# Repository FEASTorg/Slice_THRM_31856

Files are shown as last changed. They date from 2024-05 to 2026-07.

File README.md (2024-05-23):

<div align="center">
  <!-- Title: -->
  <a href="https://github.com/uwo-fast">
    
  </a>
  <h2><a href="https://github.com/uwo-fast/Slice_THRM"> Slice THRM </a></h2>
  <!-- Labels: -->
  <!-- First row: -->
  <a href="https://github.com/uwo-fast/.github/blob/main/collaborating.md">
    
  </a>
  <a href="https://github.com/uwo-fast/.github/blob/main/contributing.md">
    
  </a>
  <a href="https://www.appropedia.org/Category:FAST_literature_reviews">
    
  </a>
  <a href="https://certification.oshwa.org/">
    
    <!-- img src="https://img.shields.io/badge/OSHWA-Certified-darkgreen?style=flat-square" height="20" alt="OSHWA" -->       <!-- img src="https://img.shields.io/badge/OSHWA-Pending-darkorange?style=flat-square" height="20" alt="OSHWA" -->
  </a>
  <a href="https://osf.io/">
    
  </a>
  <a href="https://doi.org">
    
  </a>
  <!-- Second row: -->
  <br>
  <a href="https://github.com/uwo-fast/Slice_THRM/blob/main/LICENSE">
    
  </a>
  <a href="https://github.com/uwo-fast/Slice_THRM">
    
  </a>
  <a href="https://github.com/uwo-fast/Slice_THRM/issues">
    
  </a>
  <a href="https://github.com/uwo-fast/Slice_THRM/network/members">
    
  </a>
  <a href="https://github.com/uwo-fast/Slice_THRM/stargazers">
    
  </a>
  <!-- Short description: -->
  <h3>Thermocouple Reader Slice for BREAD.</h3>
</div>

## Introduction
[Provide a brief introduction to the project, including the motivation and goals. Explain the significance and context of the research.]

## Project Overview
[Describe the project in more detail. This section can be split into subsections if necessary.]

## Installation
[Provide instructions for installing any necessary software or hardware components.]

## Usage
[Explain how to use the project. Include examples and screenshots if applicable.]

### Basic Usage
[Provide basic usage instructions.]

### Advanced Usage
[Provide advanced usage instructions, including any optional features or configurations.]

## Documentation
[Link to the detailed documentation if available. Provide instructions on how to access and navigate the documentation.]

## Contributing
[Explain how others can contribute to the project. Include guidelines for submitting issues, pull requests, and any coding standards.]

### Code of Conduct
[Link to the project's code of conduct if available.]

## License
[State the license under which the project is distributed. Include a link to the full license text.]

## Acknowledgements
[Acknowledge any contributors, collaborators, funding sources, or organizations that supported the project.]

## Contact
[Provide contact information for the project maintainer(s) or lead researcher(s). Include an email address or a link to a contact form.]

---

<div align="center">
  <p>
    
    
  </p>
</div>

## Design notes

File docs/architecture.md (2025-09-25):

---
title: "Architecture Overview"
description: "High-level architecture: electrical, firmware, and mechanical design notes."
---

Overview of the electrical, firmware, and mechanical design of this Slice.

## 🧠 Purpose

<!-- Briefly describe the function of the Slice -->

This Slice is designed to ...

## 🔌 Interfaces

| Signal | Connector | Direction | Voltage | Notes |
| --- | --- | --- | --- | ----- |
| ... | ... | ... | ... | ... |

## 🪛 MCU Pin Mapping

| MCU Pin | Function | Net | Notes |
| --- | --- | --- | ----- |
| ... | ... | ... | ... |

## 🔋 Power Domains

- Logic power: ...
- High-current domain: ...

## 🧩 Mechanical

- Mounting pattern: ...
- Dimensions: ...
- Notes: ...

---

<!-- Optional: Add block diagrams or images under docs/assets/ -->

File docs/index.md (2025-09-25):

---
title: "Slice THRM 31856 Documentation"
description: "Overview and entry page for Slice THRM 31856 project documentation."
nav_exclude: true
---

Welcome to the Slice THRM 31856 project documentation.

## Board Renders

<figure style="display:inline-block; text-align:center; margin:10px;">
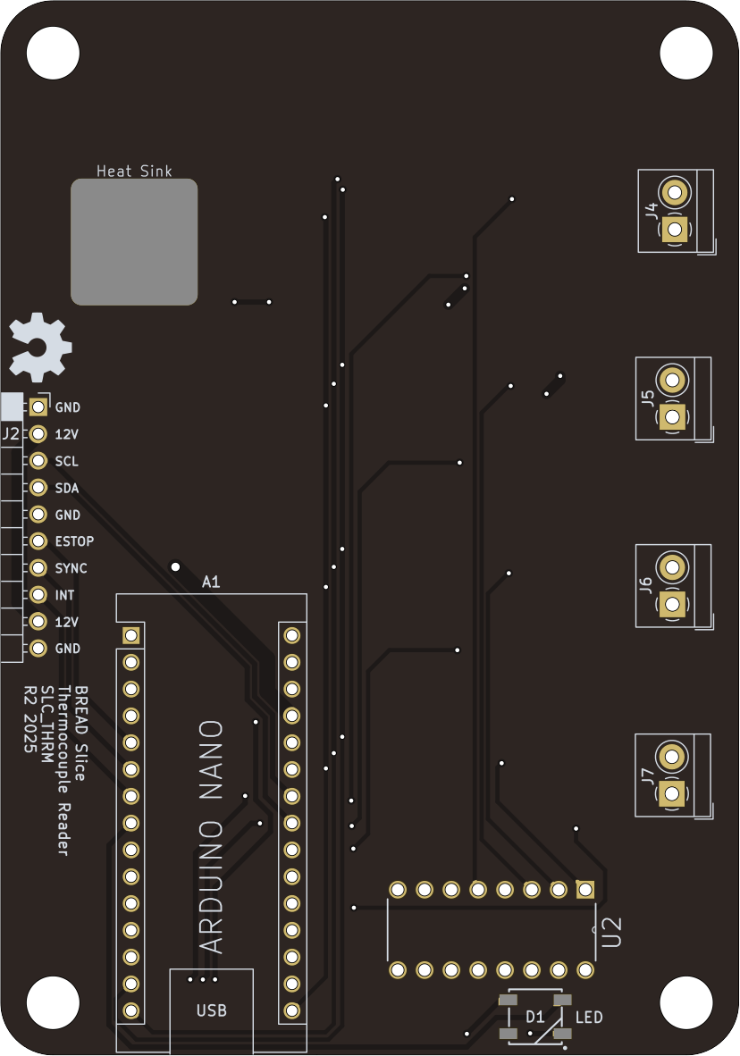
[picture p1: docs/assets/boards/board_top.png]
Board Top
  
  <figcaption>Top</figcaption>
</figure>

<figure style="display:inline-block; text-align:center; margin:10px;">
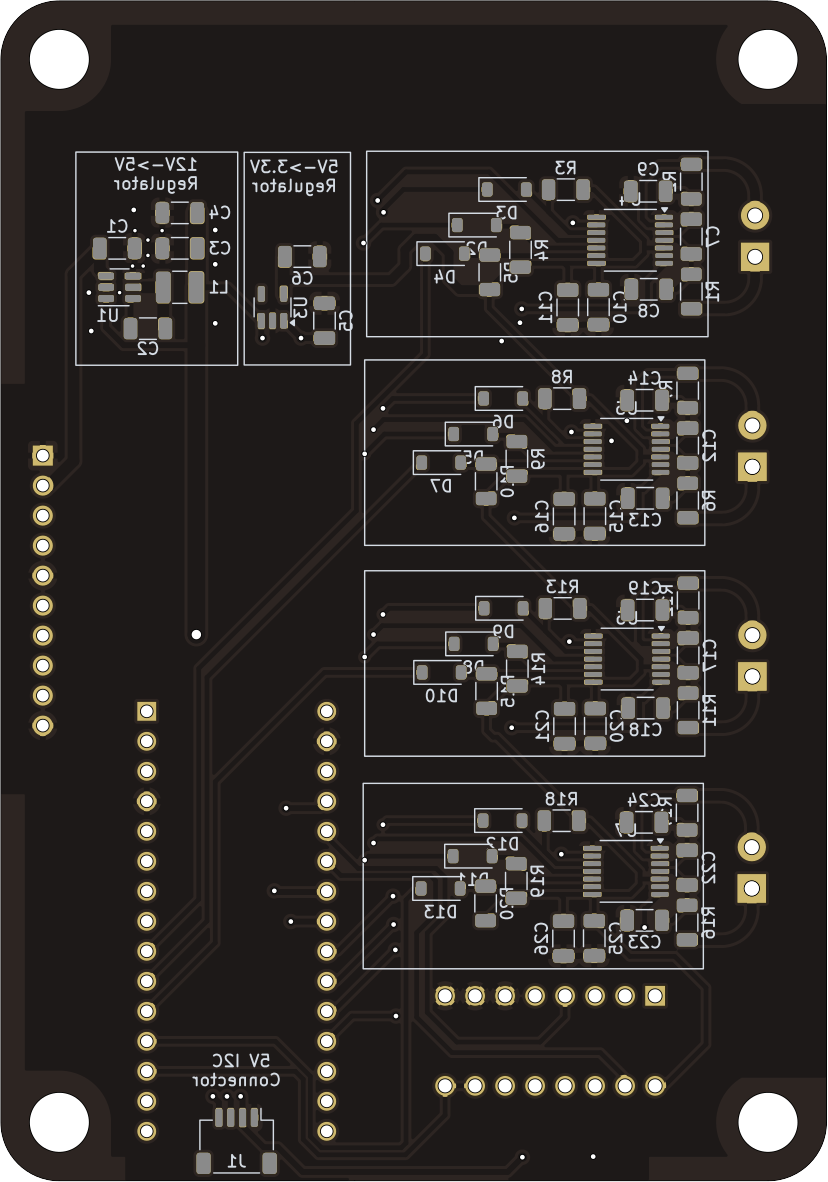
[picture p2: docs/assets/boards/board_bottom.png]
Board Bottom
  
  <figcaption>Bottom</figcaption>
</figure>

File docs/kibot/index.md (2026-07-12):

---
title: "KiBot Outputs"
description: "Index for KiBot-generated PCB artifacts."
layout: "page"
---

These are the docs & KiBot Outputs for Slice THRM 31856

The following files were generated from the latest PCB build:

- [Schematic.pdf](./Schematic.pdf)
- [PCB.pdf](./PCB.pdf)
- [kibot.log](./kibot.log)
- [BREAD_Slice-bom.html](./BREAD_Slice-bom.html)
- [BREAD_Slice-ibom.html](./BREAD_Slice-ibom.html)

_Last updated automatically on 2026-07-12 at 03:55:23 UTC by KiBot via GitHub Actions._

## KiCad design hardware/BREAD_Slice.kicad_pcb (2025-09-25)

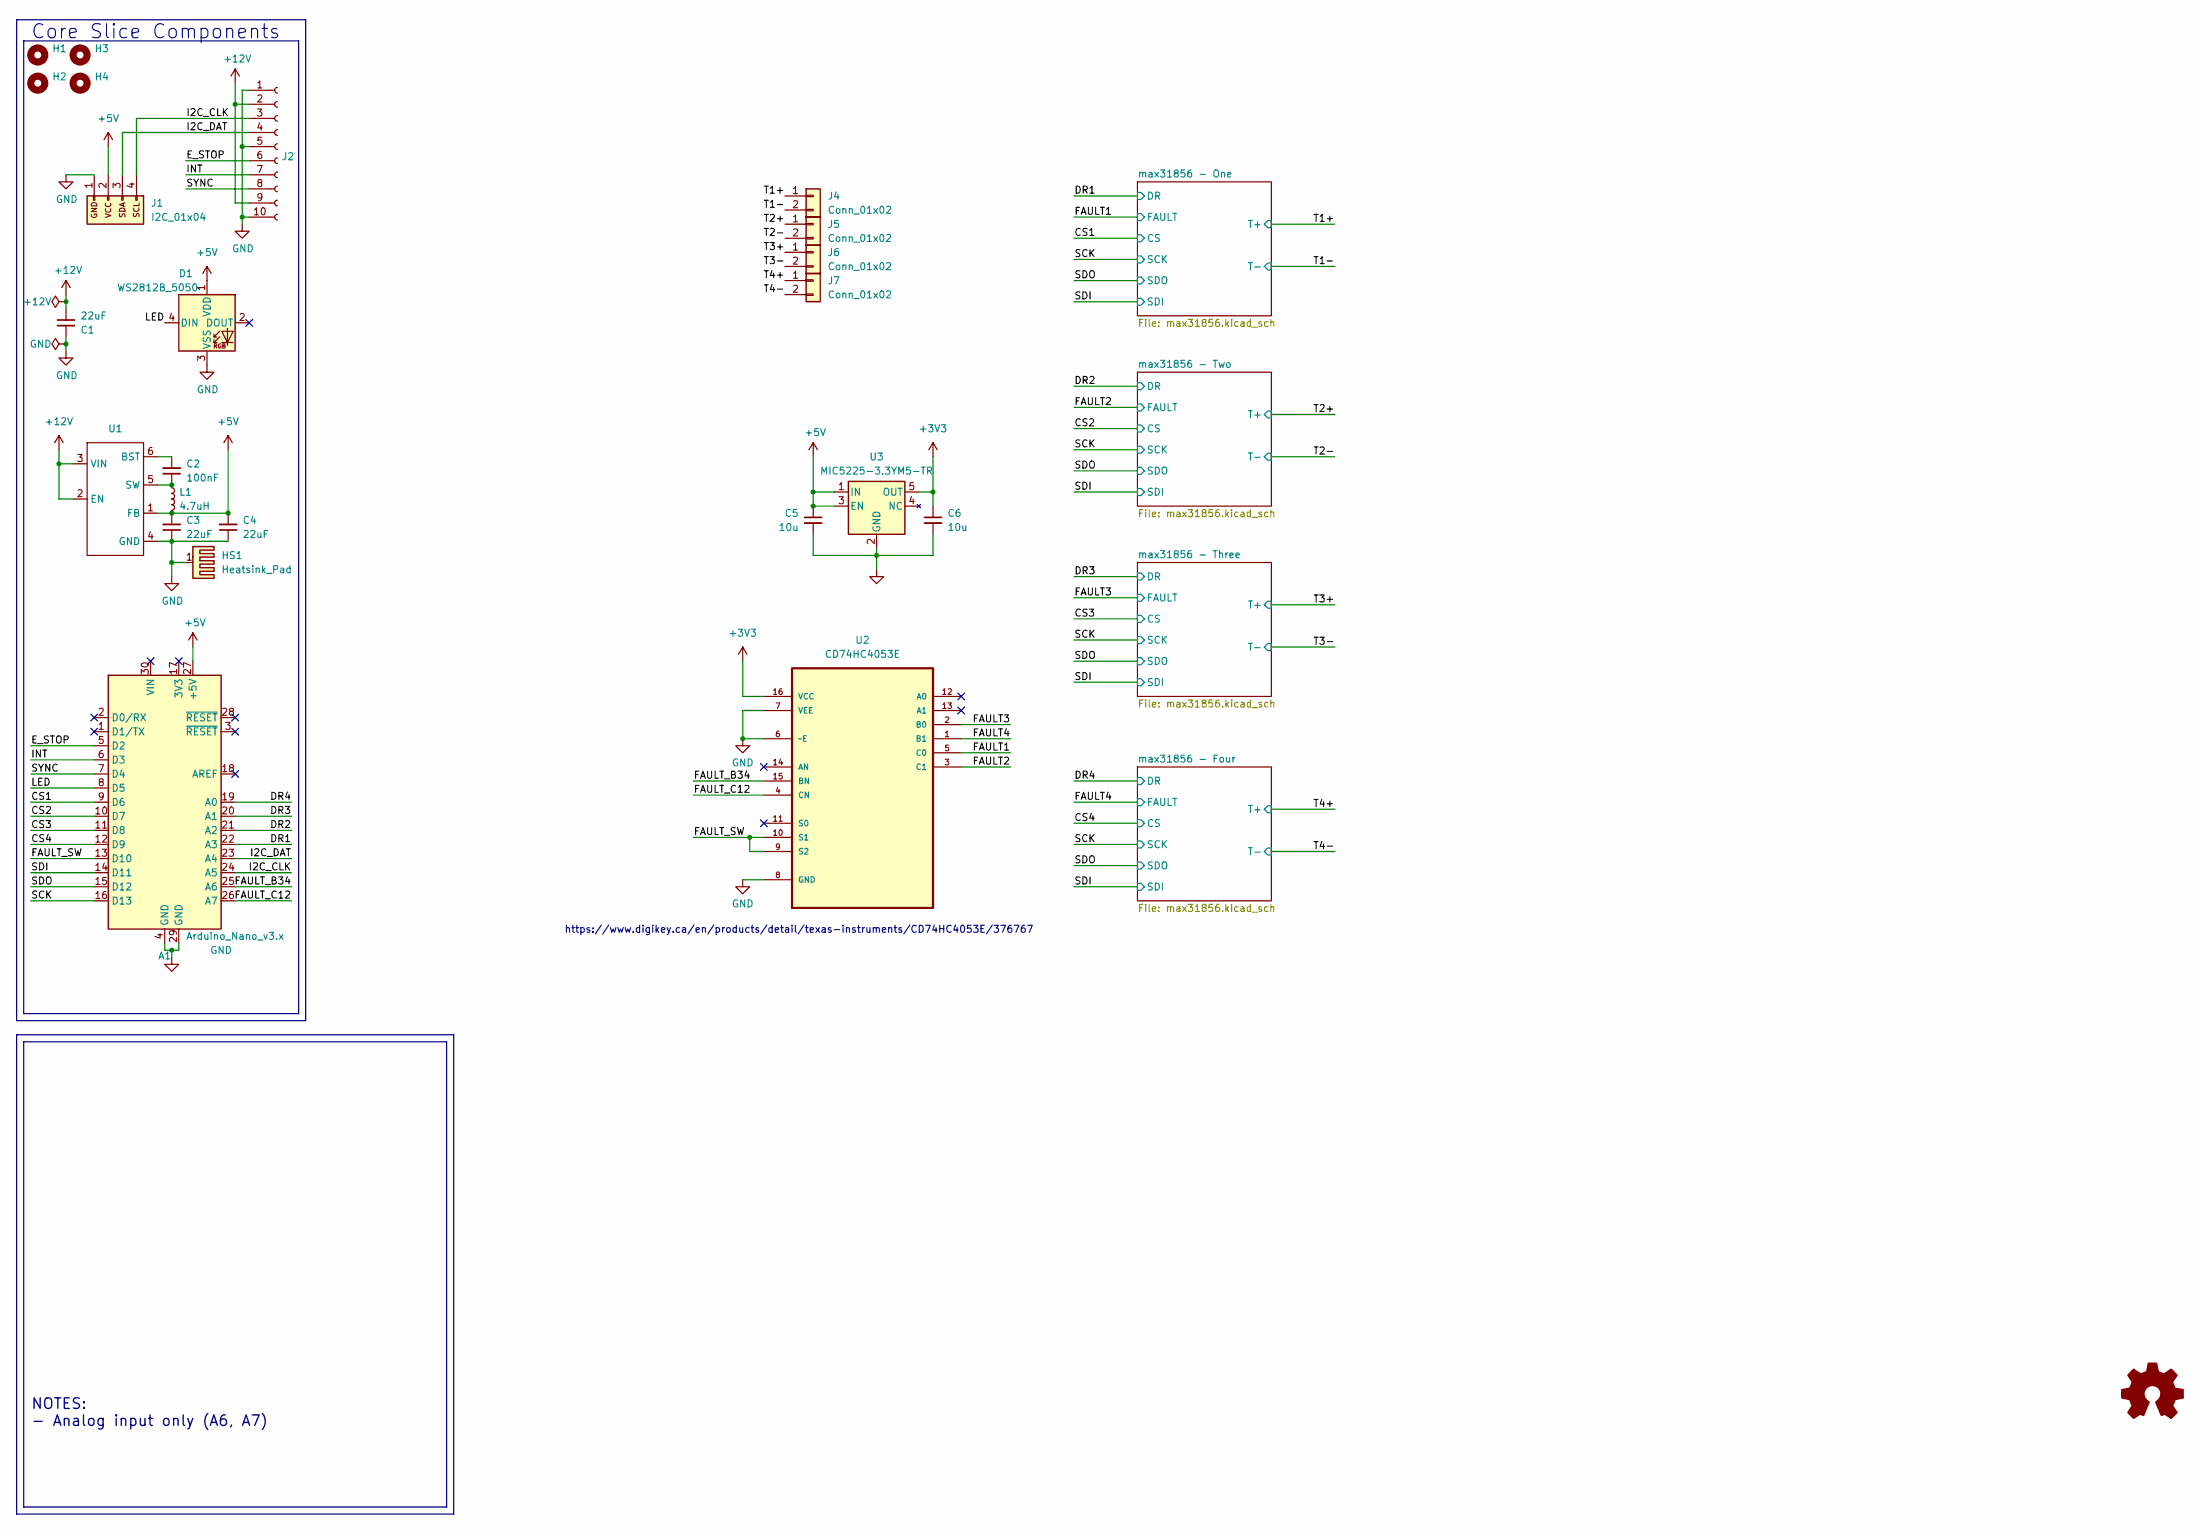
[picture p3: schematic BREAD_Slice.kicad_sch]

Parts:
A1: Arduino_Nano_v3.x; Arduino_Nano
C1, C3, C4: 22uF; C_1206_3216Metric
C2: 100nF; C_1206_3216Metric
C5, C6: 10u; C_1206_3216Metric
D1: WS2812B_5050; WS2812-5050-4PIN
H1, H2, H3, H4: MountingHole; MountingHole_5mm
HS1: Heatsink_Pad; Thermal Pad
J1: I2C_01x04; JST_SH_SM04B-SRSS-TB_1x04-1MP_P1.00mm_Horizontal
J2: Conn_01x10_Female; PinSocket_1x10_P2.54mm_Horizontal
J4, J5, J6, J7: Conn_01x02; TerminalBlock_4Ucon_1x02_P3.50mm_Horizontal
L1: 4.7uH; L_1210_3225Metric
U1: TSOT-23-6
U2: CD74HC4053E; DIP254P762X508-16; MPN CD74HC4053E
U3: MIC5225-3.3YM5-TR; SOT-23-5

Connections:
+3V3: C6.1, U2.16 (VCC), U3.5 (OUT); also elsewhere on the board
+5V: A1.27 (+5V), C3.2, C4.2, C5.1, D1.1 (VDD), J1.2, L1.2, U1.1 (FB), U3.1 (IN), U3.3 (EN)
+12V: C1.2, J2.2, J2.9, U1.2 (EN), U1.3 (VIN)
/CS1: A1.9 (D6); also elsewhere on the board
/CS2: A1.10 (D7); also elsewhere on the board
/CS3: A1.11 (D8); also elsewhere on the board
/CS4: A1.12 (D9); also elsewhere on the board
/DR1: A1.22 (A3); also elsewhere on the board
/DR2: A1.21 (A2); also elsewhere on the board
/DR3: A1.20 (A1); also elsewhere on the board
/DR4: A1.19 (A0); also elsewhere on the board
/E_STOP: A1.5 (D2), J2.6
/FAULT1: U2.5 (C0); also elsewhere on the board
/FAULT2: U2.3 (C1); also elsewhere on the board
/FAULT3: U2.2 (B0); also elsewhere on the board
/FAULT4: U2.1 (B1); also elsewhere on the board
/FAULT_B34: A1.25 (A6), U2.15 (BN)
/FAULT_C12: A1.26 (A7), U2.4 (CN)
/FAULT_SW: A1.13 (D10), U2.9 (S2), U2.10 (S1)
/I2C_CLK: A1.24 (A5), J1.4, J2.3
/I2C_DAT: A1.23 (A4), J1.3, J2.4
/INT: A1.6 (D3), J2.7
/LED: A1.8 (D5), D1.4 (DIN)
/SCK: A1.16 (D13); also elsewhere on the board
/SDI: A1.14 (D11); also elsewhere on the board
/SDO: A1.15 (D12); also elsewhere on the board
/SYNC: A1.7 (D4), J2.8
/T1+: J4.1; also elsewhere on the board
/T1-: J4.2; also elsewhere on the board
/T2+: J5.1; also elsewhere on the board
/T2-: J5.2; also elsewhere on the board
/T3+: J6.1; also elsewhere on the board
/T3-: J6.2; also elsewhere on the board
/T4+: J7.1; also elsewhere on the board
/T4-: J7.2; also elsewhere on the board
GND: A1.4 (GND), A1.29 (GND), C1.1, C3.1, C4.1, C5.2, C6.2, D1.3 (VSS), HS1.1, J1.1, J2.1, J2.5, J2.10, U1.4 (GND), U2.6 (~E), U2.7 (VEE), U2.8 (GND), U3.2 (GND); also elsewhere on the board
unnamed: C2.2, U1.6 (BST)
unnamed: C2.1, L1.1, U1.5 (SW)

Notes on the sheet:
NOTES: - Analog input only (A6, A7)
Core Slice Components
https://www.digikey.ca/en/products/detail/texas-instruments/CD74HC4053E/376767

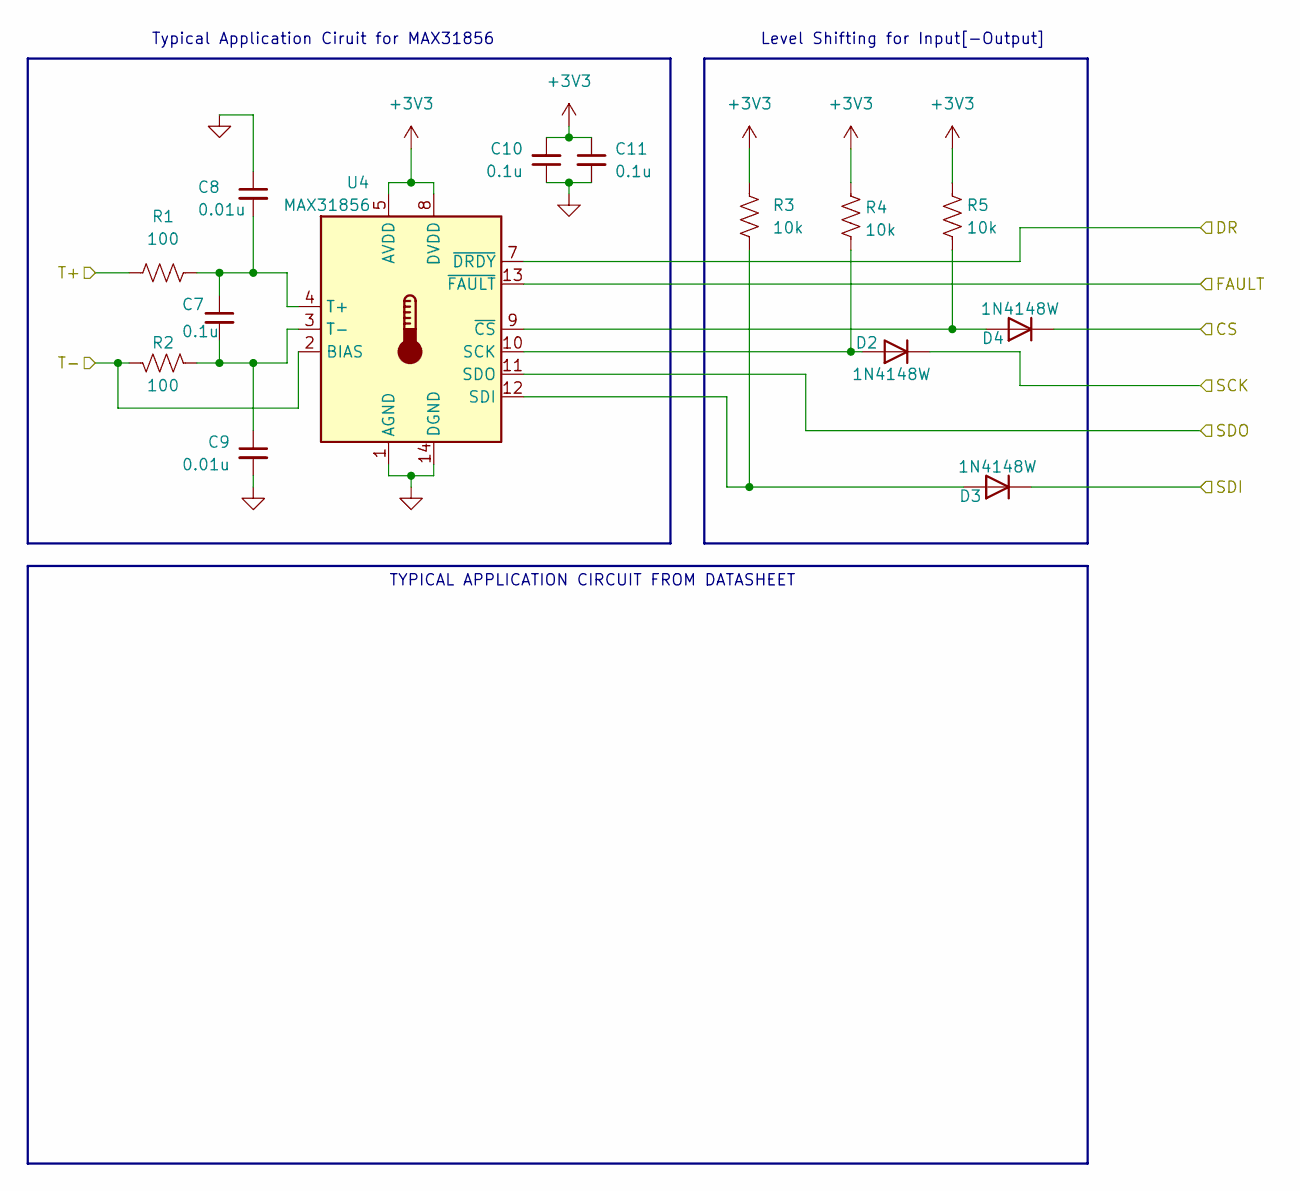
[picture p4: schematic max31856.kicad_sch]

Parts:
C7, C10, C11: 0.1u; C_1206_3216Metric
C8, C9: 0.01u; C_1206_3216Metric
D2, D3, D4: 1N4148W; D_SOD-123
R1, R2: 100; R_1206_3216Metric
R3, R4, R5: 10k; R_1206_3216Metric
U4: MAX31856; TSSOP-14_4.4x5mm_P0.65mm

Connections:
+3V3: C10.2, C11.1, R3.1, R4.1, R5.1, U4.5 (AVDD), U4.8 (DVDD); also elsewhere on the board
/CS1: D4.1 (K); also elsewhere on the board
/DR1: U4.7 (~DRDY); also elsewhere on the board
/FAULT1: U4.13 (~FAULT); also elsewhere on the board
/SCK: D2.1 (K); also elsewhere on the board
/SDI: D3.1 (K); also elsewhere on the board
/SDO: U4.11 (SDO); also elsewhere on the board
/T1+: R1.1; also elsewhere on the board
/T1-: R2.1, U4.2 (BIAS); also elsewhere on the board
GND: C8.1, C9.2, C10.1, C11.2, U4.1 (AGND), U4.14 (DGND); also elsewhere on the board
unnamed: D2.2 (A), R4.2, U4.10 (SCK)
unnamed: D3.2 (A), R3.2, U4.12 (SDI)
unnamed: D4.2 (A), R5.2, U4.9 (~CS)
unnamed: C7.1, C8.2, R1.2, U4.4 (T+)
unnamed: C7.2, C9.1, R2.2, U4.3 (T-)

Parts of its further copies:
C12, C15, C16, C17, C20, C21, C22, C25, C26: 0.1u; C_1206_3216Metric
C13, C14, C18, C19, C23, C24: 0.01u; C_1206_3216Metric
D5, D6, D7, D8, D9, D10, D11, D12, D13: 1N4148W; D_SOD-123
R6, R7, R11, R12, R16, R17: 100; R_1206_3216Metric
R8, R9, R10, R13, R14, R15, R18, R19, R20: 10k; R_1206_3216Metric
U5, U6, U7: MAX31856; TSSOP-14_4.4x5mm_P0.65mm

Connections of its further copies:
+3V3: C15.2, C16.1, C20.2, C21.1, C25.2, C26.1, R8.1, R9.1, R10.1, R13.1, R14.1, R15.1, R18.1, R19.1, R20.1, U5.5 (AVDD), U5.8 (DVDD), U6.5 (AVDD), U6.8 (DVDD), U7.5 (AVDD), U7.8 (DVDD); also elsewhere on the board
/CS2: D7.1 (K); also elsewhere on the board
/CS3: D10.1 (K); also elsewhere on the board
/CS4: D13.1 (K); also elsewhere on the board
/DR2: U5.7 (~DRDY); also elsewhere on the board
/DR3: U6.7 (~DRDY); also elsewhere on the board
/DR4: U7.7 (~DRDY); also elsewhere on the board
/FAULT2: U5.13 (~FAULT); also elsewhere on the board
/FAULT3: U6.13 (~FAULT); also elsewhere on the board
/FAULT4: U7.13 (~FAULT); also elsewhere on the board
/SCK: D5.1 (K), D8.1 (K), D11.1 (K); also elsewhere on the board
/SDI: D6.1 (K), D9.1 (K), D12.1 (K); also elsewhere on the board
/SDO: U5.11 (SDO), U6.11 (SDO), U7.11 (SDO); also elsewhere on the board
/T2+: R6.1; also elsewhere on the board
/T2-: R7.1, U5.2 (BIAS); also elsewhere on the board
/T3+: R11.1; also elsewhere on the board
/T3-: R12.1, U6.2 (BIAS); also elsewhere on the board
/T4+: R16.1; also elsewhere on the board
/T4-: R17.1, U7.2 (BIAS); also elsewhere on the board
GND: C13.1, C14.2, C15.1, C16.2, C18.1, C19.2, C20.1, C21.2, C23.1, C24.2, C25.1, C26.2, U5.1 (AGND), U5.14 (DGND), U6.1 (AGND), U6.14 (DGND), U7.1 (AGND), U7.14 (DGND); also elsewhere on the board
unnamed: D5.2 (A), R9.2, U5.10 (SCK)
unnamed: D6.2 (A), R8.2, U5.12 (SDI)
unnamed: D7.2 (A), R10.2, U5.9 (~CS)
unnamed: D8.2 (A), R14.2, U6.10 (SCK)
unnamed: D9.2 (A), R13.2, U6.12 (SDI)
unnamed: D10.2 (A), R15.2, U6.9 (~CS)
unnamed: D11.2 (A), R19.2, U7.10 (SCK)
unnamed: D12.2 (A), R18.2, U7.12 (SDI)
unnamed: D13.2 (A), R20.2, U7.9 (~CS)
unnamed: C12.1, C13.2, R6.2, U5.4 (T+)
unnamed: C12.2, C14.1, R7.2, U5.3 (T-)
unnamed: C17.1, C18.2, R11.2, U6.4 (T+)
unnamed: C17.2, C19.1, R12.2, U6.3 (T-)
unnamed: C22.1, C23.2, R16.2, U7.4 (T+)
unnamed: C22.2, C24.1, R17.2, U7.3 (T-)

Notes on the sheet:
Level Shifting for Input[-Output]
Typical Application Ciruit for MAX31856
TYPICAL APPLICATION CIRCUIT FROM DATASHEET

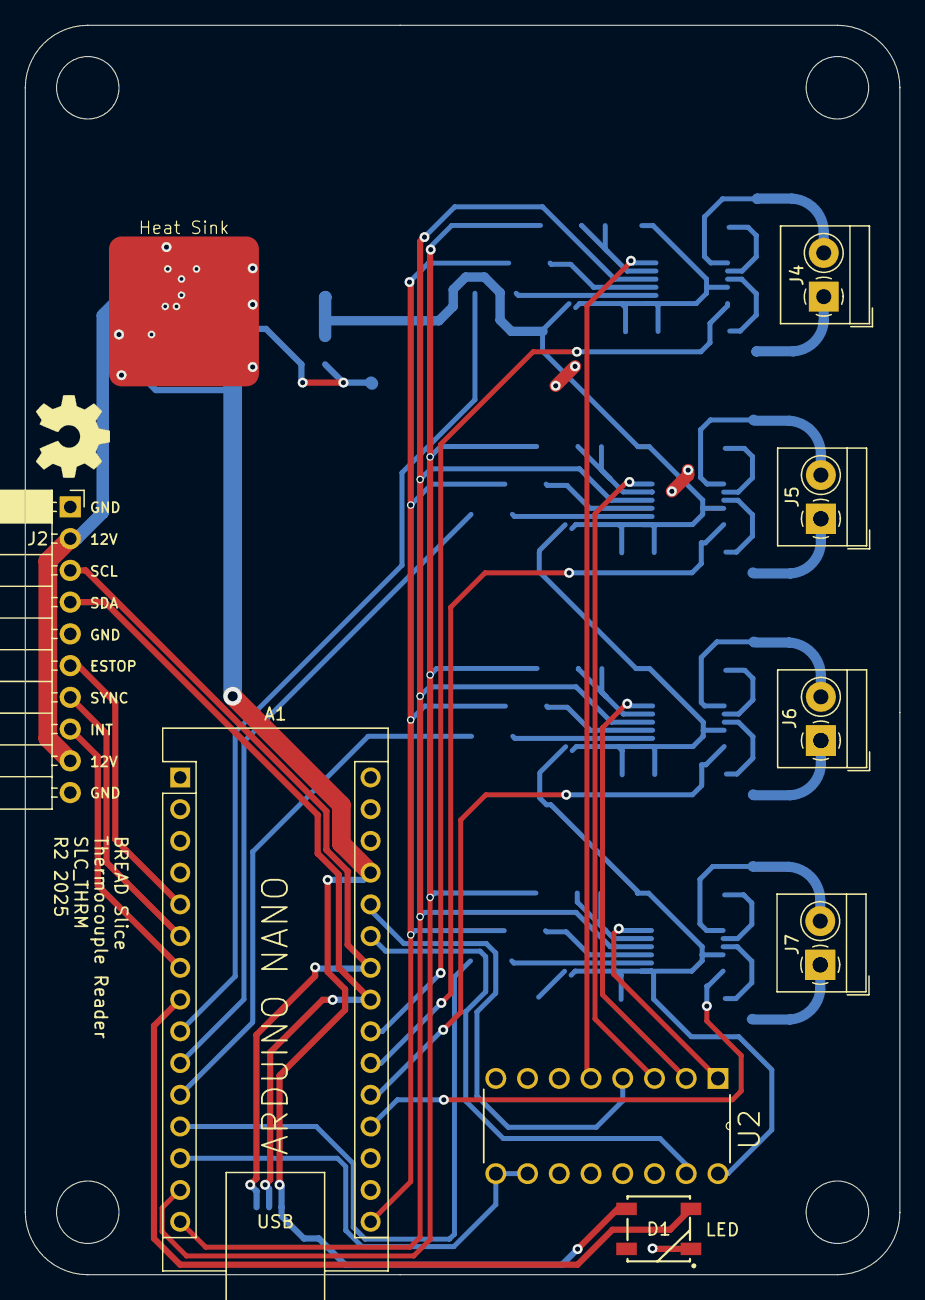
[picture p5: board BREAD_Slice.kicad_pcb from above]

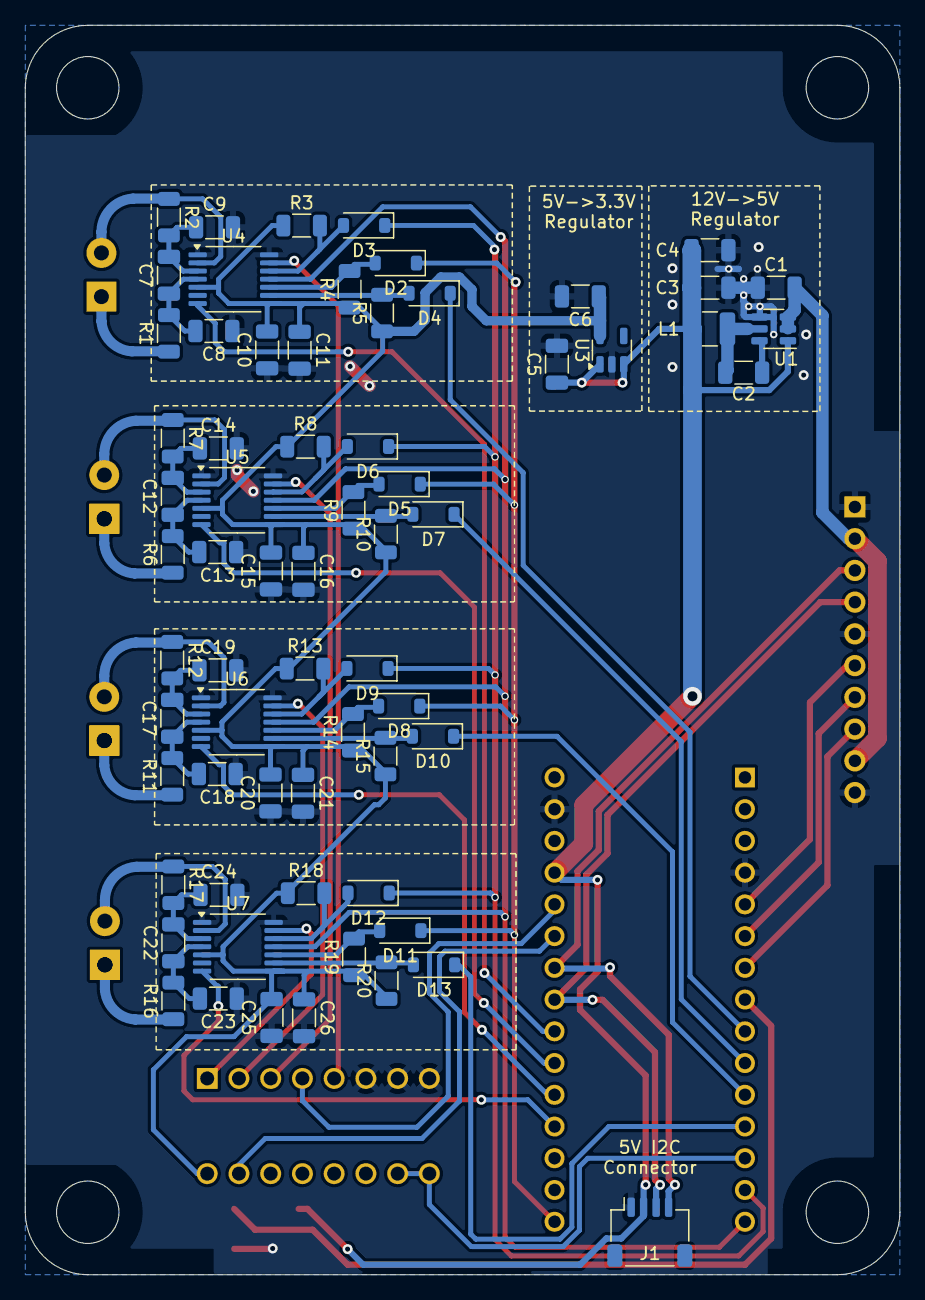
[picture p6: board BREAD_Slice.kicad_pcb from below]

Board: 2 copper layers, 70.0 x 100.0 mm, 80 parts (66 on the bottom side), 58 nets.

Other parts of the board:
Logo1: Logo_Open_Hardware_Small; OSHW-Symbol_6.7x6mm_SilkScreen

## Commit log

2024-09-07 updated + checked schem and pcb with updated template
    [BREAD_Slice.kicad_pcb, BREAD_Slice.kicad_sch, SLC_THRM.csv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]
2024-09-12 removed unneeded top level 10k clk pull up (one on each max already
    [BREAD_Slice.kicad_pcb, BREAD_Slice.kicad_sch]
2025-04-19 minor tweaks
    [BREAD_Slice.kicad_pcb, BREAD_Slice.kicad_sch, max31855k.kicad_sch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]
2025-09-25 clean out docs
    [BOM_TEMP.ods, SLC_THRM.csv]
2025-09-25 initial commit after split
    [BREAD_Slice.kicad_pcb, BREAD_Slice.kicad_sch, max31855k.kicad_sch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]
2025-09-25 hw: fix erc and drc errors; need to double check the diode and levelshift ic pathes can be independently toggled before prod
    [BREAD_Slice.kicad_pcb, BREAD_Slice.kicad_sch, max31856.kicad_sch]
2025-09-25 📄 KiBot index + board renders (auto)
